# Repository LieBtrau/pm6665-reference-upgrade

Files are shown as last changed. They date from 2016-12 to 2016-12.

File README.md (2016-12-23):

# pm6665-reference-upgrade
Improved 10MHz oscillator for the PM6665 frequency counter.

The basic version of the PM6665 has a tunable Pierce oscillator with a 74HCU04.  
20 years later and with a **€5 budget**, we can do much better than that.  
The [hardware](../../wiki/BRD161205 R0) uses a VCTCXO with a **frequency stability of 500ppb** over the -40°C..85°C range.  The potmeter allows to calibrate for the initial 2ppm frequency offset of the oscillator.  

# Calibration
* For calibrating you'll need a frequency source that is even better than this oscillator.  Preferably, that reference is also cheap.  The **GPSDO** (GPS disciplined oscillator) is a widely used solution.  If you want it cheaper (and with less accuracy), you can take the 1PPS output of a Quectel L86-M33 GPS module.  This 1Hz pulse has a < 15ns accuracy, which is 15ppb.  
* **Yearly calibration** is needed, because the frequency of the VCTCXO will drift away by 1ppm/year.
*  [Some cheap custom hardware](../../wiki/BRD161206 R0) has been designed that allows to calibrate the oscillator.

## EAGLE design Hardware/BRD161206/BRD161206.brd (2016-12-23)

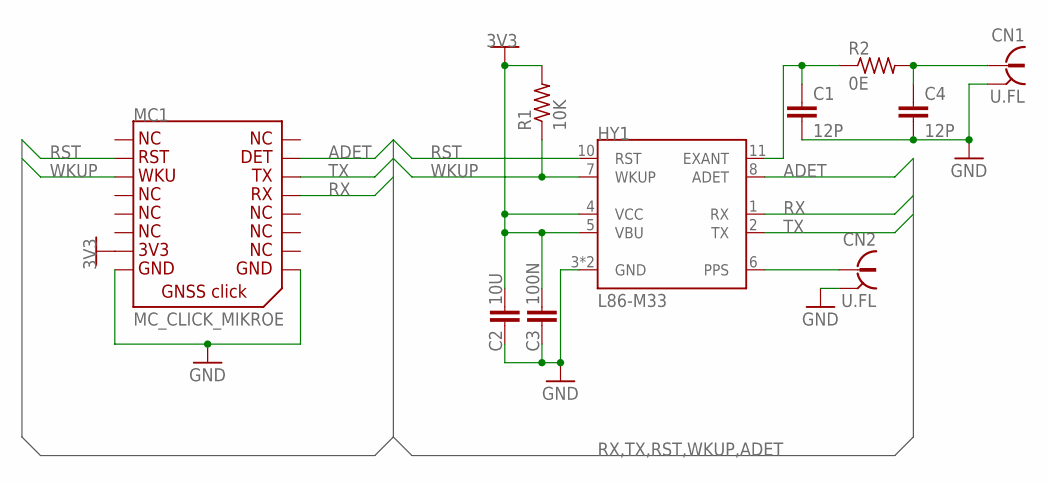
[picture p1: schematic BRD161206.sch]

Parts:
C1, C4: 12P; CA_0603
C2: 10U; CA_1206
C3: 100N; CA_1206
CN1, CN2: U.FL; CN_RF_U.FL_MALE
HY1: L86-M33; HY_GNSS_L86-M33
MC1: MC_CLICK_MIKROE
R1: 10K; RE_1206
R2: 0E; RE_0603

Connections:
3V3: C2.1, C3.1, HY1.4 (VCC), HY1.5 (VBU), MC1.P$7, R1.2
ADET: HY1.8 (ADET), MC1.P$15
GND: C1.2, C2.2, C3.2, C4.2, CN1.2A (OUTER), CN1.2B (OUTER), CN2.2A (OUTER), CN2.2B (OUTER), HY1.3 (GND), HY1.12 (GND), MC1.P$8 (8), MC1.P$9
unnamed: C1.1, HY1.11 (EXANT), R2.1
unnamed: CN2.1 (INNER), HY1.6 (PPS)
unnamed: C4.1, CN1.1 (INNER), R2.2
RST: HY1.10 (RST), MC1.P$2
RX: HY1.1 (RX), MC1.P$13
TX: HY1.2 (TX), MC1.P$14
WKUP: HY1.7 (WKUP), MC1.P$3, R1.1

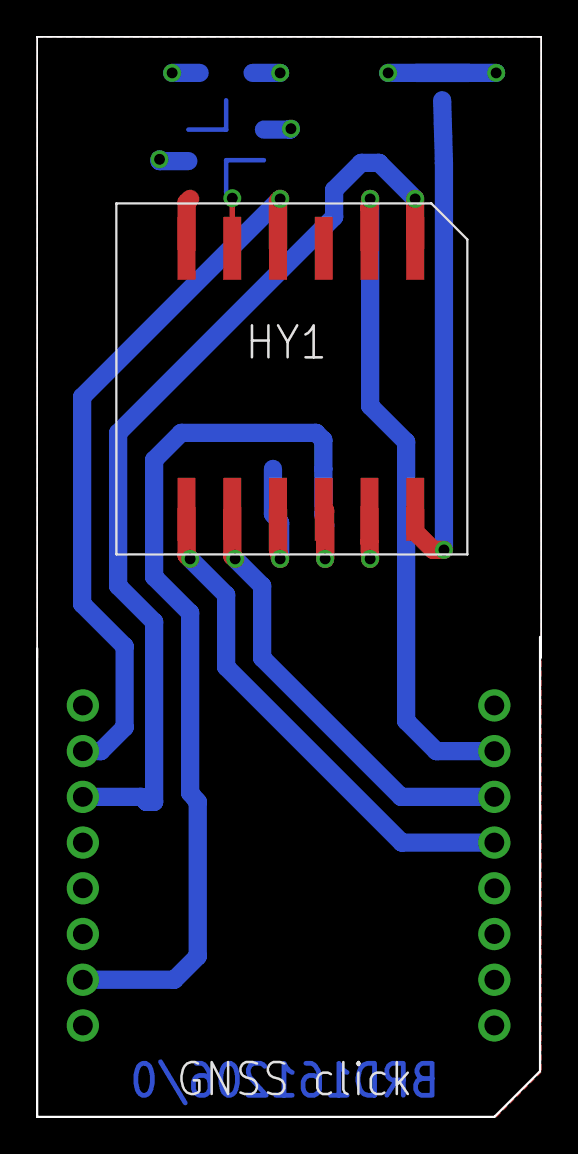
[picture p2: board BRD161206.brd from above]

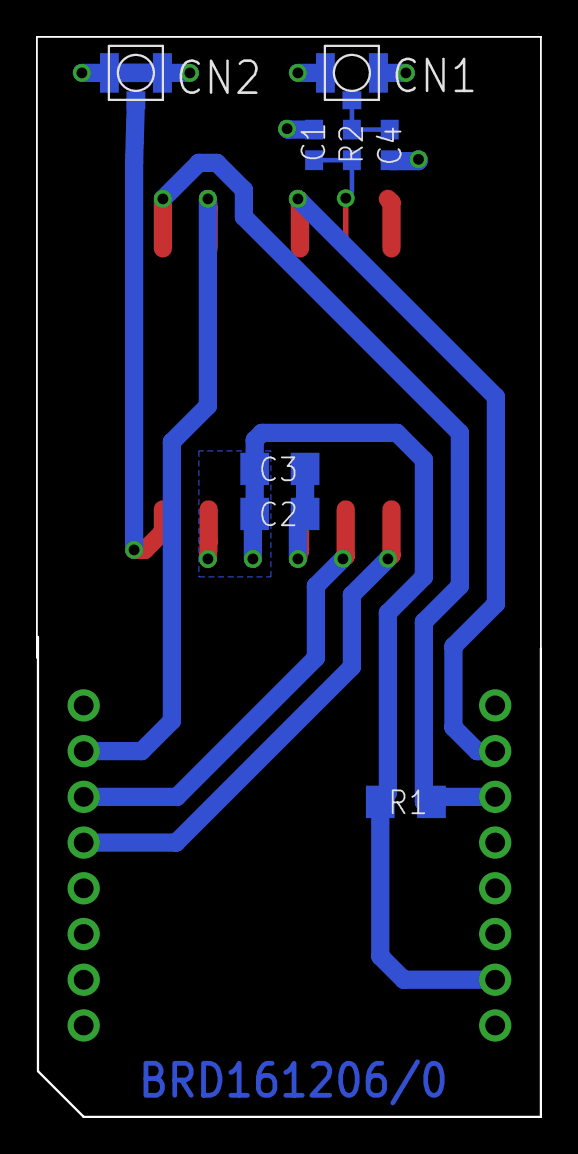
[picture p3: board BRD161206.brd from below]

Board: 2 copper layers, 28.0 x 60.0 mm, 11 parts (8 on the bottom side), 10 nets.

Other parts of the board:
U$2: MC_FRAME_A5

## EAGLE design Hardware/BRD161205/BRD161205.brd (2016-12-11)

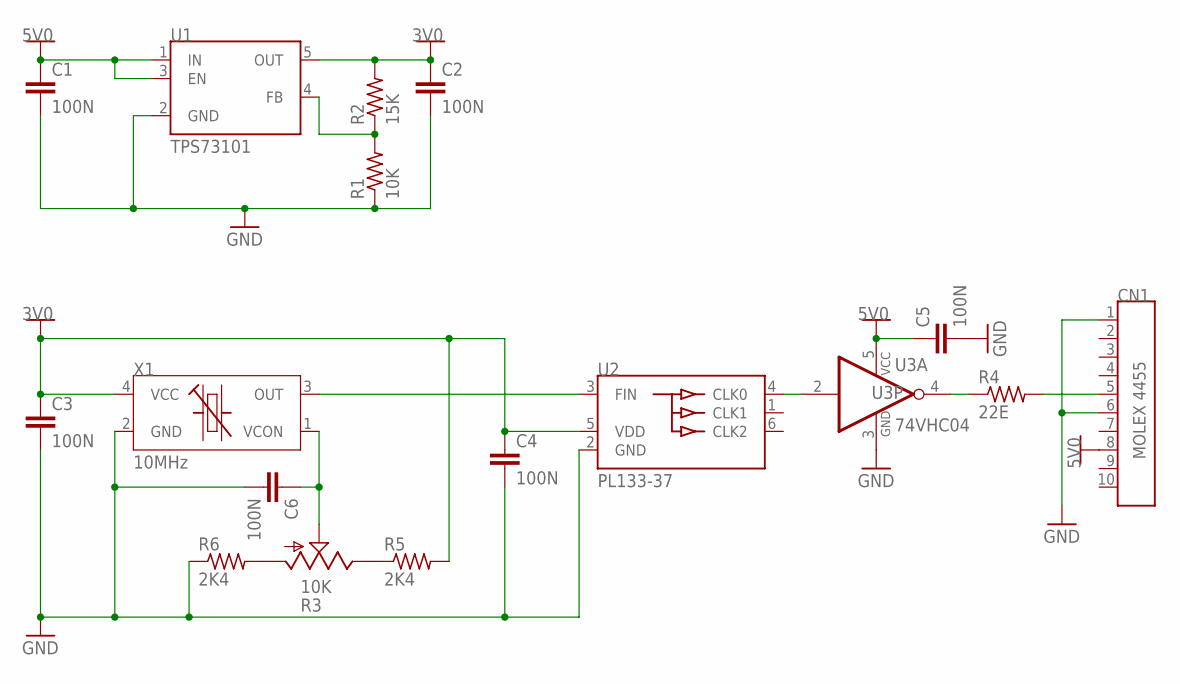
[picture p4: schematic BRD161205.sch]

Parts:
C1, C2, C3, C4, C5, C6: 100N; CA_1206
CN1: MOLEX 4455; CN_HDR1X10_90D_P254_MOLEX_4455
R1: 10K; RE_1206
R2: 15K; RE_1206
R3: 10K; RE_TRIM_TH_90D_P25
R4: 22E; RE_1206
R5, R6: 2K4; RE_1206
U1: TPS73101; SC_SOT23-5
U2: PL133-37; SC_SOT23-6
U3: 74VHC04; SC_SOT23-5
X1: 10MHz; XT_3225

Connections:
3V0: C2.1, C3.1, C4.1, R2.2, R5.2, U1.5 (OUT), U2.5 (VDD), X1.4 (VCC)
5V0: C1.1, C5.1, CN1.8, U1.1 (IN), U1.3 (EN), U3.5 (VCC)
GND: C1.2, C2.2, C3.2, C4.2, C5.2, C6.2, CN1.1, CN1.6, R1.1, R6.1, U1.2 (GND), U2.2 (GND), U3.3 (GND), X1.2 (GND)
unnamed: R1.2, R2.1, U1.4 (FB)
unnamed: C6.1, R3.2, X1.1 (VCON)
unnamed: U2.4 (CLK0), U3.2 (I)
unnamed: U2.3 (FIN), X1.3 (OUT)
unnamed: R4.1, U3.4 (O)
unnamed: CN1.5, R4.2
unnamed: R3.3, R5.1
unnamed: R3.1, R6.2

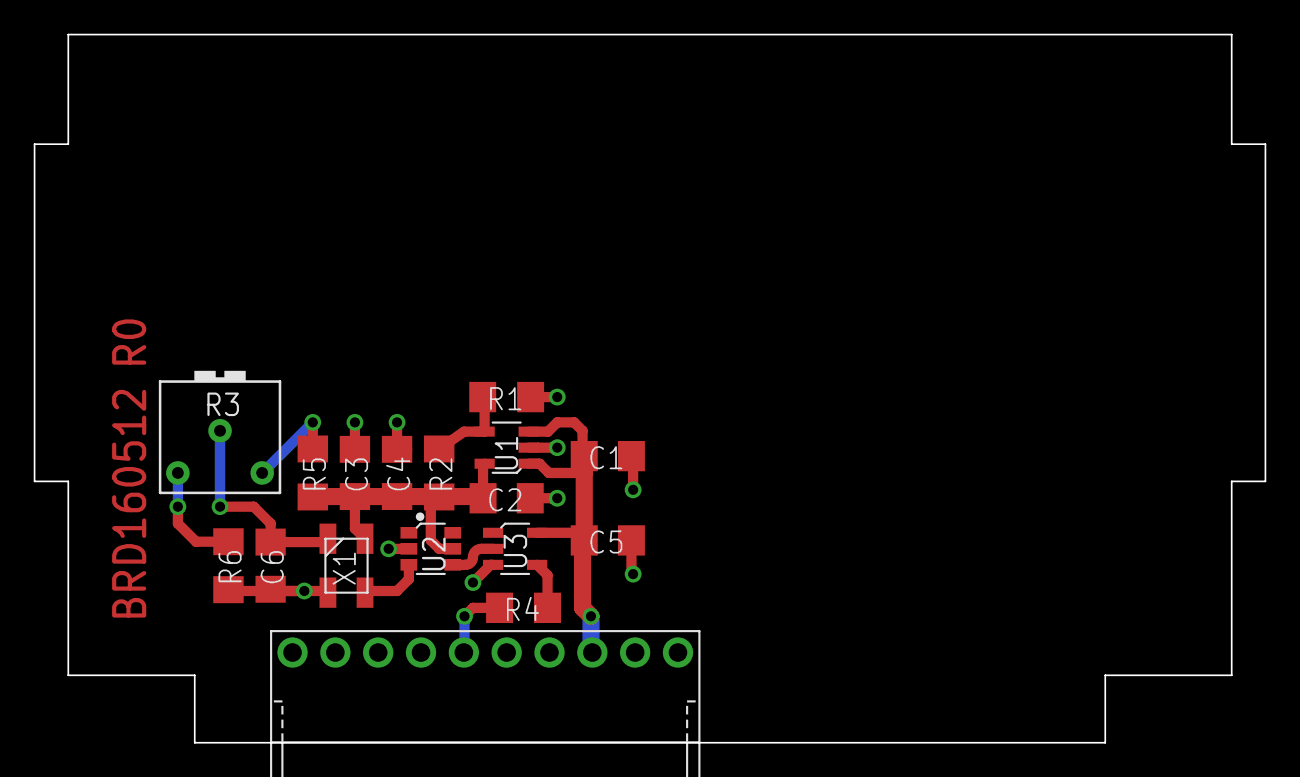
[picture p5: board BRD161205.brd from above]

Board: 2 copper layers, 73.0 x 42.0 mm, 19 parts (0 on the bottom side), 11 nets.

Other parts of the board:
DRILEGEND: DRILEGEND
U$6: FR_FRAME_A5

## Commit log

2016-12-10 fully routed, not cleaned up
    [BRD161205.brd, BRD161205.sch]
2016-12-11 BRD161205 R0
    [BRD161205.brd, BRD161205.sch]
2016-12-20 BRD161206 R00.0x
    [BRD161206.brd, BRD161206.sch]
2016-12-20 Adding info about calibrating the oscillator
2016-12-23 Adding BRD number
    [BRD161206.brd]
